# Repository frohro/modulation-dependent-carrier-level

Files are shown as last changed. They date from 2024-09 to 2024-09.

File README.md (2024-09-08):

# AWR MDCL Board
The YSE50 Amplitude Modulation Compandor (AMC) board for the ABB (ASEA Brown Bovari) SK-52 transmitters was redesigned  at AWR because we wanted a way to automatically reduce the transmitter power in real-time based on signal-to-noise ratio measurements in the target area.  It also provides us an opportunity to change the modulation-dependent carrier level (MDCL) automatically in real-time, based on the program content and/or the signal-to-noise ratio in the target area.  

This design should work with any transmitter using an ABB PSM (pulse step modulator) for AM or SW broadcasting designed in the 1980s or 1990s. It replaces the YSE 50 or YSE 21 PCBs in the PSM.  I suspect it should work with any transmitter using the YSE 21 or YSE 50.  These boards cost around \\$90,000 around the turn of the century, but you should be able to build this one for about $150 each in 2024, the most expensive parts are the DIN connectors that mate the board to the transmitter.  These boards are far better, because they use software to do the MDCL and facilitate experimentation and optimization.

## MDCL
Adventist World Radio (AWR) on Guam uses modulation-dependent carrier level (MDCL) which is a way of modifying the transmitted AM signal so it uses less power than standard amplitude modulation while hopefully not reducing the listenership.  AM was designed so receivers could be built easily and inexpensively using the technology available in the early 20th century.  A sinusoid at the radio frequency would be modulated (have its amplitude adjusted) as the desired audio signal, $m(t)$, went up and down.  If the radio frequency (RF) sine wave was $A cos(\omega_c t)$ and the audio signal to be transmitted was $m(t)$ where $|m(t)| < 1$, the transmitted signal, $v(t)$ is given by $A(1+m(t))cos(\omega_c t)$. Keeping the magnitude of the audio signal less than one makes $m(t)$ easy to remove from $v(t)$ with an envelope detector enabling very simple receivers to be constructed.  Unfortunately, there is no information in the $1$ term of $(1 + m(t))$, but it does take energy to send it.  If the audio is very soft so that $m(t) << 1$, and the goal is to transmit the information in $m(t)$, it seems especially wasteful.  (Note: Even a public address system playing an analog audio signal like $m(t)$ isn't an equal cost per bit of information.  Loud signals require more power, but they don't always contain more information.  Sometimes the quiet whisper of a friend is worth far more than the loud talk going on.  But for AM modulation the $1$ term has almost nothing to do with the $m(t)$, so it indeed seems a waste to send, at least in a certain sense.)

There are two different types of MDCL, Dynamic Carrier Control (DCC) and Amplitude Modulation Companding (AMC).  

### DCC
DCC reduces the $1$ term in $1 + m(t)$, so less carrier power is transmitted when less is needed, keeping the percentage modulation closer to 100% where the peaks of $m(t) = 1$.   The  DCC signal would be $v_{DCC}(t) = A(k(t)+m(t))cos(\omega_c t)$ .  Because the factor $k < 1$ DCC saves some energy that would have been sent in the carrier perhaps unnecessarily.  It is a slowly varying function of time compared to $m(t)$, so we often think of it as a constant, just $k$. Suppose $k$ was reduced to zero when $m(t) = 0$, then other interfering signals would likely be heard by the receiver instead of silence because most receivers have automatic gain control (AGC) which adjusts the gain up when the signal goes down.  To combat this, $k$ is not usually reduced all the way down to zero.  This leaves a flat carrier for silence, which is usually strong enough that the small noise will be masked out and the receiver will produce silence.

All MDCL schemes use a fast attack slow decay signal based on the absolute value of the modulation signal.  If $m(t)$ quickly gets louder, the changes we make to the RF signal need to respond quickly, but if $m(t)$ decreases in amplitude we should respond slowly to minimize artifacts of our signal processing.  So the first step in doing MDCL is to construct this signal.  We call this signal $m_p(t) = f(|m(t)|)$ where $f$ is the fast attack, slow decay function of time.  In the old analog days, a circuit like this where the capacitor is charged based on the $R_{attack} C$ time-constant and decays based on the $R_{decay} C$ time-constant.  (Rob, replace this figure when you get your tablet-PC going again.)
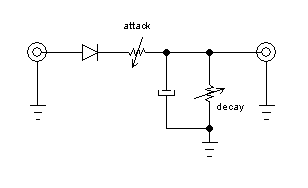
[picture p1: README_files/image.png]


would have been used.

Below, you can see how $k$ is computed as a function of $m_p(t)$ for DCC.  This function is somewhat heuristic.  The one shown is used in the YSE21 board.  Sometimes $k$ goes back up for low values of $m_p(t)$ to help silence be silent in a real receiver in the presence of interference.

```python
import matplotlib.pyplot as plt
import numpy as np

# Define the x values
x = np.linspace(0, 1, 500)

# Define the y values based on the condition
y = np.piecewise(x, [x < 0.5, x >= 0.5], [0.5, lambda x: (x-0.5)+0.5])

# Create the plot
plt.plot(x, y)

# Label the axes
plt.xlabel('$m_p(t)$')
plt.ylabel('k')

# Set the range for the axes
plt.xlim(0, 1)
plt.ylim(0, 1)

plt.title('DCC Carrier Level, k')

# Display the plot
plt.show()
```

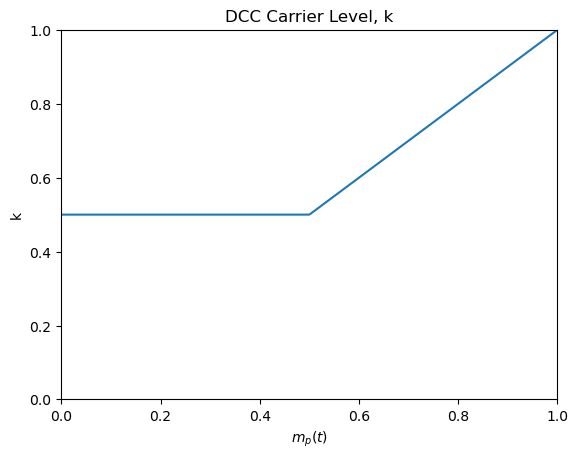
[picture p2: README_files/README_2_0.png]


### AMC
AMC takes the view that the soft or silent portions of the broadcast are more important to preserve than the loud portions.  This may be more appropriate for music rather than talk.  It adjusts the amplitude of $v(t)$, instead of just the carrier, as a function of $m_p(t)$ so  $v_{AMC} = A (A_{REL}(1+m(t)))$.  The following graph shows $A_{REL}$ as a function of $m_p(t)$.  Note again, that makes $A_{REL}$ a function of $t$, but since it is relatively slowly varying compared with $m(t)$, so we just call it $A_{REL}$.  

```python
# Define the x values
x = np.linspace(0, 1, 500)

# Define the y values based on the condition
y = np.piecewise(x, [x < 0.1, x >= 0.1], [1, lambda x: (-0.5/.9*x+1+.1*.5/.9)])

# Create the plot
plt.plot(x, y)

# Label the axes
plt.xlabel('$m_p(t)$')
plt.ylabel('$A_{REL}$')

# Set the range for the axes
plt.xlim(0, 1)
plt.ylim(0, 1.1)

plt.title('AMC Relative Signal Level, $A_{REL}$')

# Display the plot
plt.show()
```

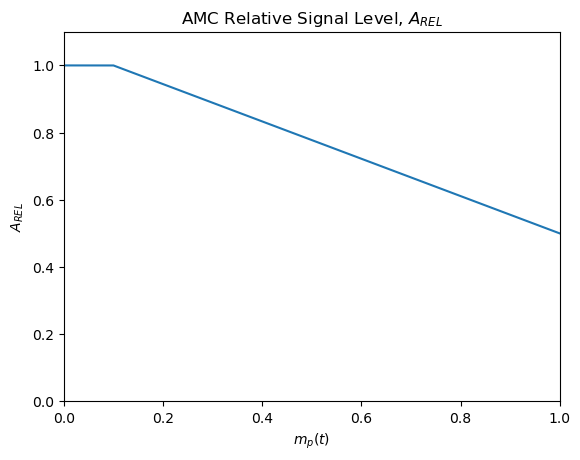
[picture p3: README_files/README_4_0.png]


AMC peak output power of the transmitter is the same as the output from the carrier alone.  For example, an SK-52 transmitter with a normal AM power level specified at 100 kW, means the carrier alone will output 100 kW average power.  On peak modulation, the output will be 400 kW because the $m(t)$ adds to the $1$ to become $2$ for 100% modulation at peaks of $m(t)$ giving $4$ times the power because power is proportional to the square of the voltage which is twice what it was for the carrier alone.  AMC thus saves power and wear and tear on the transmitter, by reducing the average power it is transmitting under larger modulation.  

There are variations on these two themes of MDCL one can dream about.  It is claimed that AMC is better for music, while DCC is better for speech.  AMC is more popular with medium wave AM stations.  It may sound better at least to some.  DCC only reduces carrier power, and that really doesn't contain any information other than silence.  Previous experiments with DCC indicated it actually sounds louder to the listener due to the way the receiver AGC and the transmitter DCC interact which is good for short wave.  AMC will save the station more money than DCC, but so would simply turning the power down.  Turning the power down is the major improvement we wish to add to the options, so we can use AMC, DCC, or ordinary AM, but only the power needed.  In the past it was not easy to measure how much power was needed, but now with Internet connected receivers, it can be done fairly easily.  Since the space weather changes the signal levels for skywave signals, this will change over time, so there will be times when less power is needed than the maximum possible.  In general a cut in power by half is only barely perceptible to the listener, so significant savings on the power bill can be expected.  The plan is to measure the signal-to-noise ratio every 15 minutes or so and change the transmitter power as appropriate.

## Transmitter Operation
AWR Guam has five ABB SK-52 100 kW transmitters.  They use the standard modulation method, where the B+ high voltage on the plate of the final amplifiers is supplied by the modulator, which produces an amplified version of the output of the MDCL output signal.  By varying this voltage on the plate of the final RF amplifier, the output signal’s amplitude is set.  This is called modulating the transmitter.   See the diagram below.
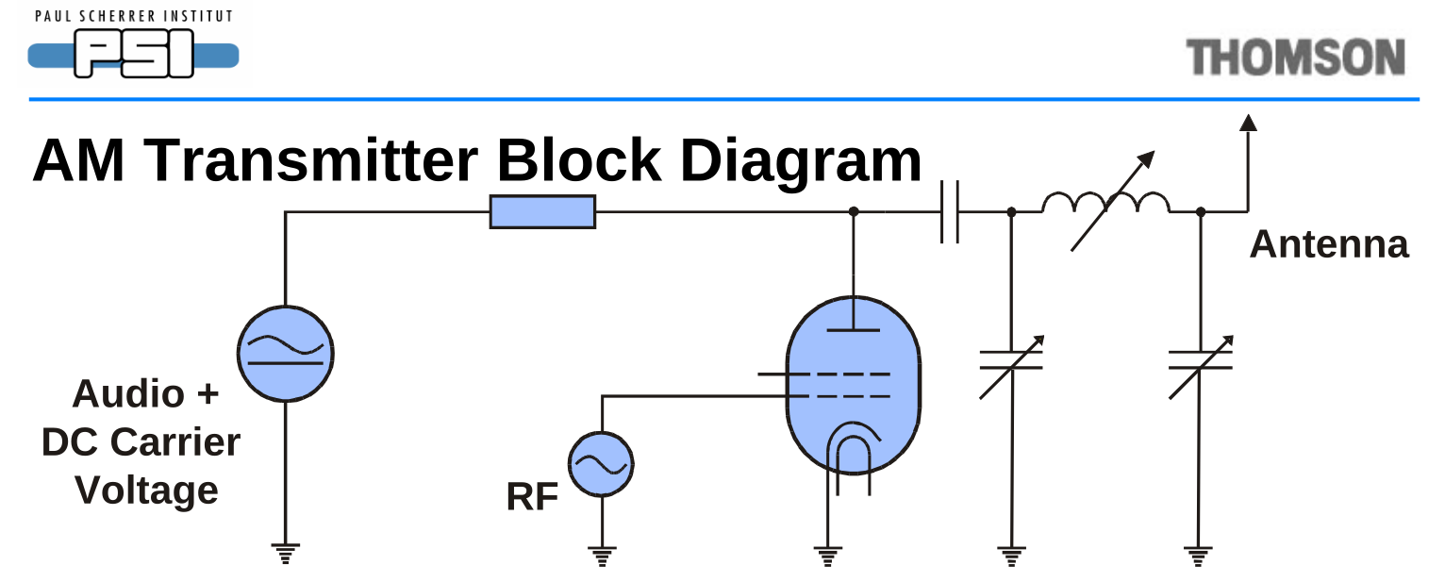
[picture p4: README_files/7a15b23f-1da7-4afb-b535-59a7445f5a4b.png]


A Pulse Step Modulator (PSM) is used to create the “Audio + DC Carrier Voltage” in the diagram above.  The PSM is essentially like a digital to analog converter where 26 voltage sources are switched in series by digital signals.  It is like a 26 level digital to analog converter with an output of 22 kV maximum.  When the AM transmitter (no MDCL) is sending silence, the PSM puts out 11 kV.  At 100% modulation where the $max (|m(t)|) = 1$, it puts out between 0 and 22 kV as the audio, $m(t)$ goes up and down.  Below is a basic diagram of a PSM.  The switches are controlled digitally and in the SK-52 are gate turn off (GTO) devices.  The blue, green, magenta and orange circular symbols are voltage sources.  (Rob, to avoid copyright, we could replace these when you have your bricked computer back.)
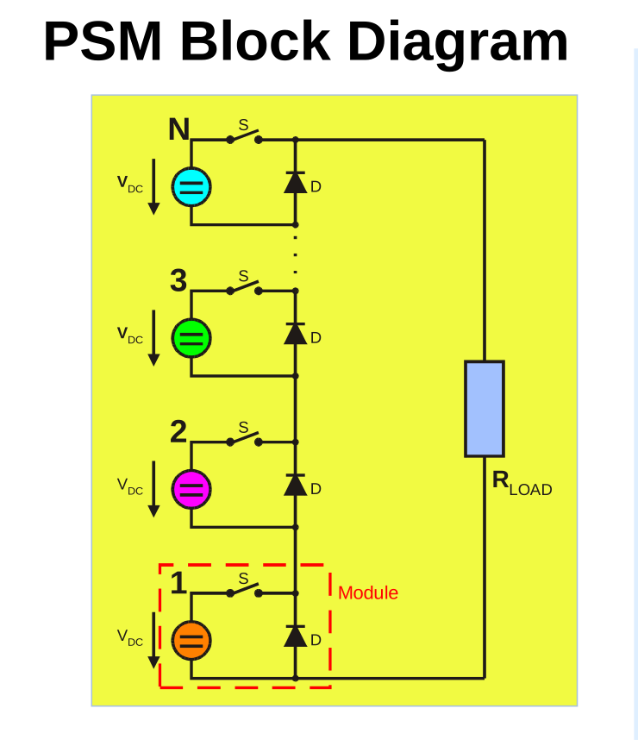
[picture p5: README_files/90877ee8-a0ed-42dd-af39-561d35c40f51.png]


The most obvious place in the circuit to incorporate a modification to the SK-52 transmitters is in the MDCL board, so YS50 was replaced.  The MDCL board is where something can be incorporated into the circuit to lower the power when a remote Internet connected receiver in the target area indicates the transmitter could cut power without significantly lowering the number of listeners.  We just add one more parameter we can control that multiplies whatever type of audio signal we have by a slowly varying "constant", that changes perhaps every 15 minutes as the signal-to-noise ratio is updated.  If this constant is called $A_{att}$, it would have a maximum value of $1$ for maximum power, and $0.707$ for half power, or $0.5$ for quarter power.  

Note in the blue AM Transmitter Block Diagram above, the screen grid in the vacuum tube.  Unless the voltage on the screen is also controlled by the MDCL board, a risk exists that the screen current will increase beyond acceptable limits.  For example if the plate of the tube is at $0$ volts, and the screen at a higher voltage, the screen will act as the plate normally would and the screen current would be way to high.  This means there is a limit to how much we can drop $A_{att}$.  A solution to this problem is to increase the resistor between the screen supply and the screen.  We were able to drop the power to 25% of maximum.  (Rob, make sure this is correct.)

We also noted a problem with the PSM protection circuitry which styll needs to be ironed out.

The transmitter has a limit to how long the modulation, $m(t)$ can exceed a certain value, so that the transmitter is not operated beyond 100 kW for longer than is good for it.  This limit is enforced in the MDCL software as well.

## Board Description

### Hardware
The hardware is based on a [PJRC Teensy 4.1 development board](https://www.pjrc.com/store/teensy41.html).  It features a 600 MHz ARM Cortex-M7 processor with FPU, nice Arduino DSP library, a USB 2.0 port and Ethernet.  The data $1+m(t)$ comes in as a 5V TTL digital 12-bit parallel signal sampled at 100 kHz.  This signal is converted to a serial signal by a pair of 74LV165 parallel to serial conversion ICs.  These also convert the 5V TTL level signals of the input data to 3.3 V logic levels.  This serial data is read into the Teensy using SPI0.  The Teensy processes the signal as needed and sends the data to a serial to parallel conversion performed by a pair of 74ACHT595 ICs, which send the result on to the next board in the transmitter.  There is a CH340G that allows use of a second USB serial port for debugging (Serial2 for the Arduino) and four connectors for the inexpensive eight bit logic analyzers from China to read the serial and parallel data.  There are a number of LEDs for indicators and debugging and some provision for connecting other signals to the Teensy in case we overlooked something.  The Teensy we are using comes with Ethernet, and we send the real-time control signals over that medium.

The Teensy has a feature that may eventually be used to eliminate the analog stages of the whole broadcast system, making the whole system at KSDA digital, from the digital audio in all the way to the PSM of the transmitter.  This feature is the USB connector on the Teensy can be made to look just like a USB sound card for a computer operating at the 44.1 kHz sample rate. I have tested the Linux sample rate conversion library runing a sinc interpolator and it looks feasible to convert from 44.1 kHz to 100 kHz in real time, leaving about half the time between 100 kHz samples for DSP.  Optical USB extenders can be used to span the distance between the transmitters and the audio distribution computer.

### Software

#### Toolchain
You can build this with the Arduino IDE using Teensyduino or with VScode.  The latter gives you a nicer environment, but the former is quicker to set up.

#### Serial Input
The SPI (SPI0) is used for the serial data transfer of the input data.  The upper four bits of the 16 bit word should be zero.  If not, you have RFI or something bad happening.  The Teensy 4.1 supports a depreciated legacy way or doing the transactions, but also has the new recommend way.  Using that method, the speed can be increased from 12 MHz to 80 MHz.  The setup function shows how to set things up, and the ISR is shown below:
// ISR function called by the interrupt that is triggered by L1
// to process the new word from the transmitter
void receive2ByteWord() // Receive 16-bit word from SPI0
{                       // Select the slave device
  SPI.beginTransaction(spiSettings);
  digitalWrite(chipSelectPin0, LOW);
  // Send a dummy byte to initiate the SPI read and receive the 16-bit word
  uint16_t dummy = 0x00;
  receivedWord = SPI.transfer16(dummy); // Deselect the slave device
  digitalWrite(chipSelectPin0, HIGH);
  validWord = 1; // Indicates that the new 16-bit word is received and ready to process
  SPI.endTransaction();
}
#### Serial Output
The SPI1 bus is used for transferring data to the serial to parallel converter so the data will be ready for a parallel read by the transmitter.  Like the serial input, the setup function gets the SPI initialized and the following code is the ISR that happens when triggered by LC.
// ISR function called by the interrupt that is triggered by L5 to send the
// processed word to the transmitter (DCC board used LC, but L5 is faster)
void send2ByteWord()
{
  SPI1.beginTransaction(spiSettings);

  digitalWrite(chipSelectPin1, LOW); //  We are not using CS1.
  SPI1.transfer16(wordToSend);       // Send the 16-bit word to the transmitter
  digitalWrite(chipSelectPin1, HIGH);
  SPI1.endTransaction();
}
DCC and MDCL Processing
uint16_t processMDCL(uint16_t one_plus_m_t)
// See the MDCL.ipynb for the theory on this.
{ // This function takes a 16-bit word whose lower 12 bits is 1+m(t) and processes it according to the MDCL algorithm
  // We could put a check for overmodulation here if wanted (Check for repeated 0's)
  if (digitalRead(SSBOnOffPin) == LOW && digitalRead(NFBereitPin) == HIGH && digitalRead(DCCOnOffPin) == HIGH)
  { // if MCDL is on
    uint16_t m_p;
    static uint16_t m_pPrevious = 0;     // store the previous m_p(t) value
    static uint16_t samplesUntilDecay = samplesPerDecay; // This is the number of samples until the decay starts

    if (one_plus_m_t < 2048)           // Find |m(t)| value where 1 + m(t) scaled to 0 to 4095
    {
      m_p = 2048 - one_plus_m_t; // This should not overflow.
    }
    else
    {
      m_p = one_plus_m_t - 2048; // This should not overflow.
    }
    #ifdef DEBUG
    uint16_t m_p_a;
    m_p_a = m_p;  // mpa is for debugging.  It is m_p without the decay.
    #endif
    // m_p(t) needs to be a fast attack, slow decay function of time
    if (m_p <= m_pPrevious) // m_p is decreasing
    { 
      m_p = m_pPrevious; // m_p(t) should not decrease
      if (samplesUntilDecay > 0) // Will decay down to close to 0 (within samplesPerDecay) if m_p(t) is not increasing
      {
        samplesUntilDecay--;
      }
      else // sammples until decay is 0, so decay one step
      {
        if (m_p > 0) m_p--; // m_p should not be decreased below zero
        samplesUntilDecay = samplesPerDecay; // Reset the decay counter
      }
    }
    else // m_p in increasing so don't decay m_p(t).  It needs to rise instantly, but samplesPerDecay needs to be reset so it is ready for the next decay.
    {
      samplesUntilDecay = samplesPerDecay; // Reset the decay counter
    }
    m_pPrevious = m_p; // Store the current m_p(t) value for the next cycle
    if (currentMDCLNumber == 0) // DCC
    {
      if (digitalRead(DCCPin) != HIGH) // Change indicator LEDs if needed
      {
        digitalWrite(DCCPin, HIGH);
        digitalWrite(AMCPin, LOW);
      }
      uint16_t dccK; // See the graph of DCC k as a function of m_p(t).  We may want to pass the 430 and 1024 parameters in someday
      if (m_p > 1024)
      {
        dccK = m_p;
      }
      else if (m_p < 430) // Using curve as used for ABB high power transmitters (> 100 kW)
      {
        dccK = 1454 - m_p;  // 1454 = 1024 + 430
      }
      else
      {
        dccK = 1024;
      }
      return percentAdjust * ((dccK + one_plus_m_t)-2048); // percentAdjust is to turn the power down
    }
    else if (currentMDCLNumber == 1) // AMC
    {
      if (digitalRead(AMCPin) != HIGH) // Change the indicator LEDs if needed
      {
        digitalWrite(DCCPin, LOW);
        digitalWrite(AMCPin, HIGH);
      }
      {
        digitalWrite(DCCPin, LOW);
        digitalWrite(AMCPin, HIGH);
      }
      float AMC_REL = (2048 - m_p / 2)/2048.0;                        // This should not overflow.
      return percentAdjust * ((AMC_REL * one_plus_m_t)); // percentAdjust < 1, is to turn the power down
    }
  }
  return percentAdjust * one_plus_m_t; // If MDCL is off, just pass the word through adjusted for desired power output
}

#### Keeping from Damaging the Transmitter by Asking for Too Much Power
The PSM manual description of YSE27 (pages 42-44) describe how long a signal that would transmit more than 100 kW is allowed.  You cannot have more than 2500 for longer than 10 mS.  If it happens, then you need to drop to the carrier level (2048) until the signal goes below the carrier level.  At first I was unable to determine if YSE27 was before or after YSE21 (the DCC unit we are replacing) so we wrote a safety routine that kept the MDCL board from violating the conditions needed for a healthy transmitter described there.  There were still possibilities of a bug that this would not catch, so I went back and finally found that YSE21 is before YSE27 in the transmitter.  It makes more sense to put this check at the end of the line, not in the DCC section, so our code was redundant, and was a possible place for bugs.  The block diagram in section 5 of Volume 7 Schematic Diagrams AF Stages (PSM), YSE-27 documents this.  I am removing our redundant code to make the software simpler.  (Rob 9/2/24).  This relieves a fear that we could ask the transmitter for more power than it could handle and it would burn up.

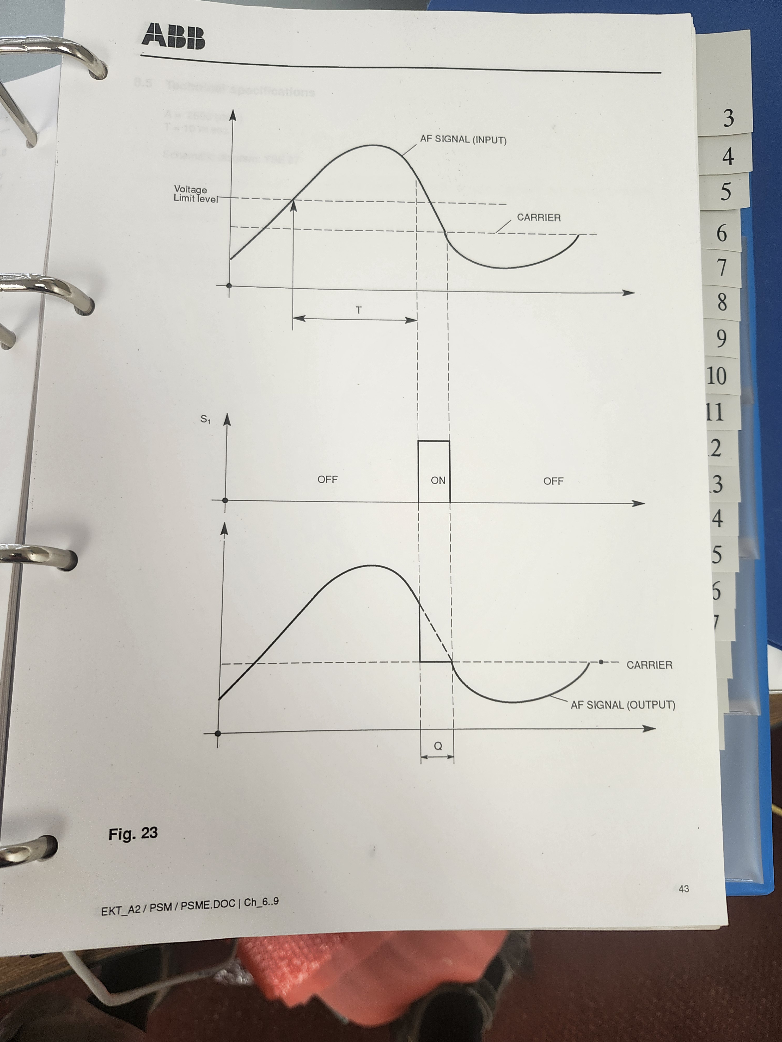
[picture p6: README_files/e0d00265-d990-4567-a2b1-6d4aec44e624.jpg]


#### Screen Modifications
The final tube screen voltage gets more and more attractive for electrons relative to the plate (anode) so an extra screen resistor was added to the screen power supply and possibly the voltage tap will be changed to reduce the screen voltage.

### Things Tested and Look Good
* SPI at 80 MHz both in and out good!
    * No data outside the 12 bit range like Ray had with the slower SPI
* Timing of SPI (input and output)
* Main loop usually happens every uS, but every 4th time it is 3.5 uS
* processMDCL with dontBurnTransmitterUP uses 300 nS (0.3 uS)  (fast enough)
* MDCL works (tested using triangle under all conditions)
* Make sure if loop() is delayed, it just keeps sending out the same wordToSend.  This will cover short timing problems, where loop() gets delayed.  It does.  
* Watch out for RFI!
### Things to test
* Different MDCL types and power levels while listening to remote receivers
* Lower voltage taps on screen power supply
### Things to Improve
* The messages in TCP/IP communication are too long.
* The code quoted in this keeps improving, making this difficult to keep up to date.  We need a better way of documenting it.
### Priorities for Rob before leaving Guam in order of Priority
* Get the MDCL board running smoothly.  Hopefully we can be running it in one of the transmitters full time by the time I leave.
    * Investigate how different MDCL methods and power levels are seen from remote receivers.
    * Documentation for the MDCL board and videos
* Finish getting the PostgreSQL database going for automated monitoring.
* Get the automated power level software going.

## Operation
#### RFI
Beware of RFI.  The PSM in the transmitter gets ">OFF" errors (meaning it is taking too long to turn off PSM modules, which is bad because the switch (GTO) dissipates power whenever it is turning on or off and the energy dissipated depends on how quickly you switch).  These appear to be caused by RF feedback into the system through the MDCL board when it is on the extender board for testing.  So only test it with it inside the transmitter case if the test involves transmitting, and do not leave any cables connected to it because they act as antennas.  If cables must be connected, use ferrite torroids to suppress common mode RF and optical fiber instead of copper wires wherever possible.

Compute what the minimum power output will be with your MDCL and make sure it does not go below 10 kW.  We could put a test in the code to not send something below 648.

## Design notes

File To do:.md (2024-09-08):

To do:
1) Clean up and refactor the code. (Make it organized, and have short files that each do their thing, and only that.)
    a) Make subprograms
        i) in seperate files
    b) Minimize global variables
    c) Make a seperate test program without all the other junk
    d) Document the programs carefully
    e) Test them
    f) Make debug code
        i) Use Serial3
        ii) Make a triangle or sine wave subprogram at 100 kHz sample rate
    g) Use Github Copilot to help organize this and speed things up (Get Ray up on it or do it yourself)
    h) Use variable names that are descriptive, match the documentation and go with that seperate block of code.
    i) Try to make the code simple, but not use too much time.
2) Learn how to operate the transmitter so two are not needed for testing (Rob)
3) Try 250 Ohm screen resistor
4) Minimize RFI possibility (No uneeded cables should be connected)
    a) Don't connect Ethernet until needed
        i) Perhaps use shorter cables or optical link.
    b) Don't connect the computer that is connected to the transmitter to power (run on batteries)
    c) Minimize the loop area for any ground loops
    d) Look for RFI with the scope
    e) Perhaps use ferrite beads if we find RFI somewhere and need to have the cable connected

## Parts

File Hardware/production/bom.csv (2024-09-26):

Designator | Footprint | Quantity | Value | LCSC Part #
C1, C11, C16, C17, C19, C2, C20, C4, C5, C6, C7, C8, C9 | 0805 | 13 | 0.1u | C49678
C10, C14 | 0603 | 2 | 10p | C1634
C18 | 0805 | 1 | 10u | C15850
D1 | D_SMA | 1 | SS14 | C2480
D10, D11, D12, D13, D3, D7, D8, D9 | 0603 | 8 | LED | C2290
D2, D4, D5, D6 | LED_3.0mm_2.54mm_lead_spacing_horizontal | 4 | HV-32H307B/260/XSYG
J1 | DIN41612_F_3x16_Male_Horizontal_THT | 1 | Top DIN
J10 | IDC-Header_2x05_P2.54mm_Vertical_SMD | 1 | Logic Analyzer SPI1 | C2843214
J11 | PinHeader_2x03_P2.00mm_Vertical_SMD | 1 | Ethernet Jack Socket | C3975167
J2 | DIN41612_F_3x16_Male_Horizontal_THT | 1 | Lower DIN
J3 | RJ45_Cetus_J1B1211CCD_Horizontal | 1 | J1B1211CCD | C910371
J4 | USB_Micro-Yuandi-G3P3-A1T2 | 1 | USB_B_Micro | C2682512
J5 | IDC-Header_2x05_P2.54mm_Vertical_SMD | 1 | Logic Analyzer SPI0 | C2843214
J6 | IDC-Header_2x05_P2.54mm_Vertical_SMD | 1 | Logic Analyzer D_In | C2843214
J7 | IDC-Header_2x05_P2.54mm_Vertical_SMD | 1 | Logic Analyzer D_Out | C2843214
J8, J9 | PinHeader_1x24_P2.54mm_Vertical | 2 | Teensy socket | C7506622
R1, R2, R3, R4 | 1206 | 4 | 75 | C17888
R10, R11, R12, R9 | 0603 | 4 | 470 | C23179
R5, R6, R7, R8 | 0805 | 4 | 100 | C17408
TP1, TP2 | TestPoint_THTPad_4.0x4.0mm_Drill2.0mm | 2 | GND
U1, U2 | TSSOP-16_4.4x5mm_P0.65mm | 2 | 74LV165 | C201716
U3, U4 | TSSOP-16_4.4x5mm_P0.65mm | 2 | 74AHCT595 | C554707
U5 | SOT-353_SC-70-5 | 1 | 74HC1G04GW,125 | C10234
U6 | SOP-16_3.9x9.9mm_P1.27mm | 1 | CH340G | C14267
U7 | TSSOP-24_4.4x7.8mm_P0.65mm | 1 | SN74LVC8T245 | C7859
Y1 | Crystal_SMD_2520-4Pin_2.5x2.0mm | 1 | 12 MHz | C963522

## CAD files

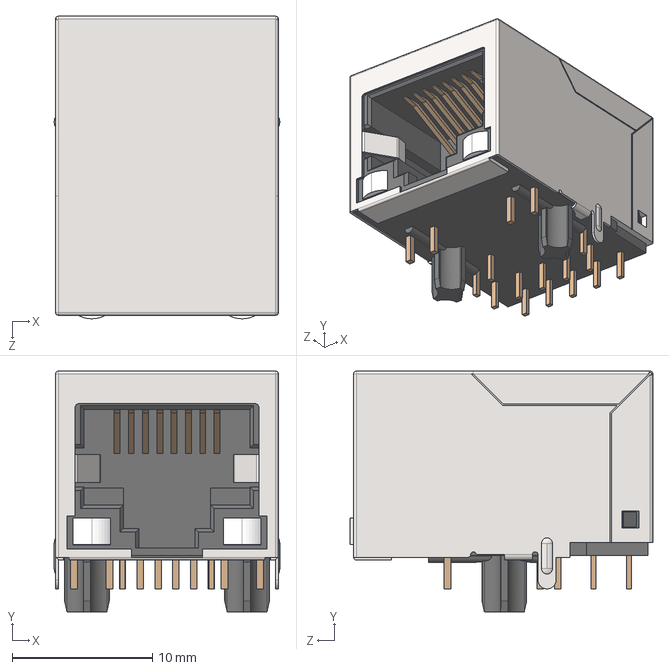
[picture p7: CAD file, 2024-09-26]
Hardware/RJ45 Connector with Integrated Magnetics.STEP
16.1 x 17.2 x 21.6 mm

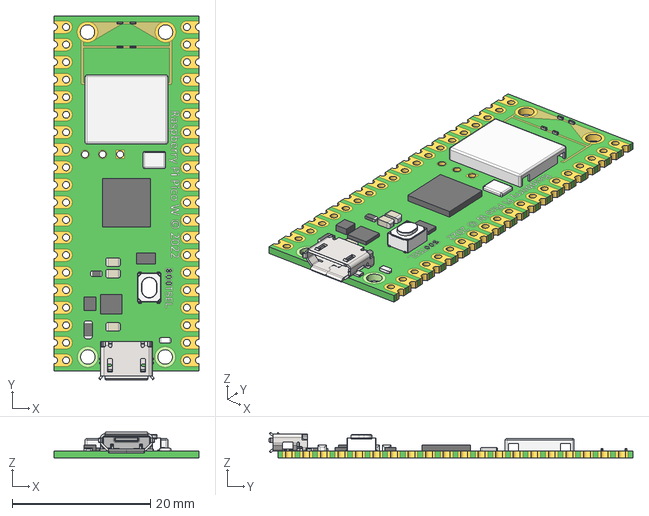
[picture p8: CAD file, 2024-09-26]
Hardware/RaspberryPi-PicoW-NoPins.step
21.0 x 52.7 x 3.71 mm

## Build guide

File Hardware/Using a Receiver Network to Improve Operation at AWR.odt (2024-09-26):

AWR Dynamic Power Control Project

Overview:

AWR’s station on Guam spends more than half a million dollars on electricity every year to spread the Gospel to countries in Asia broadcasting in the HF shortwave spectrum. Shortwave broadcasters lack the data which Internet media dissemination provides, such as how many listeners, etc., but it is not traceable like the Internet either. A person in North Korea can listen quietly under the covers with a lot less risk than using a computer or phone to listen online. AWR also buys time on other broadcast facilities around the world in places like Madagascar, Tajikistan, Austria, Germany, Uzbekistan, Taiwan, and Sri Lanka. They are paying far more to these stations than the cost of power on Guam. There is at present no regular monitoring of these stations to make sure they are delivering the programs they agreed to deliver to the prospective target areas. If you are interested, the program schedule is available here (https://awr.org/wp-content/uploads/2024/03/A24-AWR-Public-Broadcast-Schedule.pdf). The resources available online have multiplied in the past twenty years. For a number of years there have been a number of software defined radio receiver networks online that enable one to listen to shortwave radio with a web browser. For example, the KiwiSDR network is available here (http://rx.linkfanel.net/). There are receivers in AWR target areas that could be used to gather data about how well AWR can be heard. This data could be used in a number of ways.

- The data could be used to make sure the programs are receivable in the target areas.
- The data could be used to help make up the program schedule each season.
- Shortwave propagation varies with the space weather. The exact location of the receiver is not as important as one might expect. For example, usually when stations in Europe are heard in Washington State, they are heard with very similar signal strengths all up and down the West Coast. Signal strengths vary as the earth rotates and sun shines on different areas of the ionosphere. At sunrise and sunset, this is very noticeable. Often the signal can vary by more than 20 dB. For a broadcaster to increase their signal by 20 dB, the power of the transmitter would need to be raised by two orders of magnitude. Sometimes the signal strength of an AWR transmission will be 20 dB louder than necessary. Other times, for example during an aurora event, the signals may not be discernible in the target area. Hopefully, this does not happen often, but it probably does occur occasionally. If the data available online giving the signal to noise ratio was sampled every few minutes, that data could be used to adjust the transmitter power in “real time” so the signal was still good, but not unnecessarily strong. This could lower the power bill for AWR. For example, if AWR was 20 dB louder than needed, the power could be cut by a factor of 100 while that condition prevailed.
- AWR uses 4x4 dipole curtain antenna arrays. Presently, they steer the beam of the antenna in the horizontal direction using switched delay lines to target different areas. It is possible that steering the beam in the vertical direction could improve AWR’s signal in the desired target area. Online receivers could be used to investigate this, and if it varies with HF propagation conditions, it could be adjusted in real time along with the power.
- The receiver network could also be used to adjust the modulation dependent carrier level (MDCL) used in the transmitters.

The first priority for my time on Guam is to make the transmitters so the power can be controlled by a computer signal. After studying the transmitter it appears the best way to do that is to replace the MDCL board.

MDCL:

AWR uses modulation dependent carrier level (MDCL) which is a way of modifying the transmitted AM signal so it uses less power. Standard amplitude modulation (AM) was designed so receivers could be built easily and inexpensively using the technology available in the early 20th century. A sinusoid at the radio frequency would be modulated (have its amplitude adjusted) as the desired audio signal, m(t), went up and down. If the radio frequency (RF) sine wave was { cos left ( { %omega_c ~ t } right ) } and the audio signal to be transmitted was { m left ( t right ) } where |m(t)| < 1, the transmitted signal, v(t) is given by A ( 1 + m(t) ) cos(%omega_c t) . Keeping the magnitude of the audio signal less than one makes m(t) easy to remove from v(t) and enabled very simple receivers to be constructed. Unfortunately, there is no information in the 1 term of (1 + m(t)), because it does take energy to send it. If the audio is very soft so than m(t) << 1, and the goal is to transmit the information in m(t), it is especially wasteful.

There are two different types of MDCL, Dynamic Carrier Control (DCC) and Amplitude Modulation Companding (AMC).

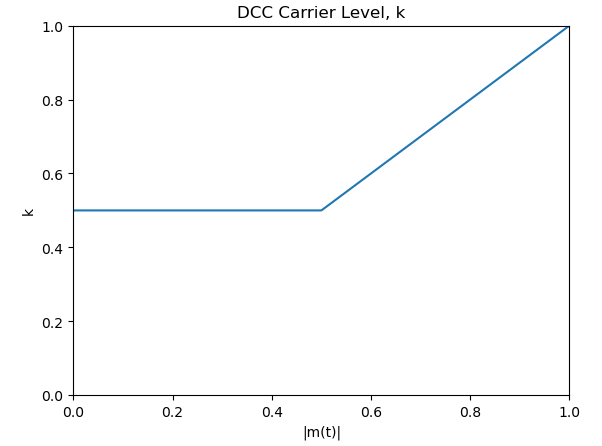
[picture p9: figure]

DCC reduces the 1 term in v(t), so less carrier power is transmitted when less is needed, keeping the same amount of m(t) transmitted so that the magnitude of m(t) was always less than or equal to the new constant, k, creating the “carrier”. The DCC signal would be v_{DCC}(t) = A ( k + m(t) ) . If k was reduced to zero when m(t) = 0, other interfering signals would likely be heard by the receiver instead of silence, because most receivers have automatic gain control (AGC) which adjusts the gain up when the signal goes down. To combat this, k is not usually reduced all the way down to zero. This leaves a flat carrier for silence, that will usually be strong enough that the small noise will be masked out and the receiver will produce silence. The graph on the previous page shows how the carrier level, k, was adjusted in the first DCC circuit the present transmitters on Guam used.

AMC takes the view that the soft or silent portions of the broadcast are more important to preserve than the loud portions. This may be more appropriate for music rather than talk. It adjusts the amplitude of v(t), instead of just the carrier, as a function of |m(t)| so v_{AMC}(t) = A (A_{REL}) ( 1 + m(t) ) .

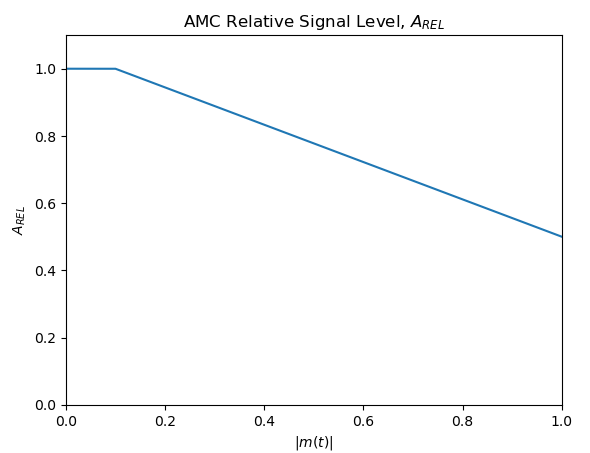
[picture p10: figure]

In recent years AWR has been using AMC, even though its programming is primarily talk instead of music because it reduced their power bill more than DCC would have. This is because AMC reduces the whole signal, not just the carrier, so the part of the signal carrying information is also reduced when it is louder. The actual information would have been better transferred with DCC, but the differences are only slight. Both ways reduce the power bill. Using remote receivers we may be able to tell what the best algorithm and adjustment is best. Furthermore, we could use AI to recognize the type of program being broadcast, music or speech, and perhaps change the MDCL as a function of the program type.

MDCL generally has a fast attack, slow decay, so it gradually turns the power down, and quickly turns it back up.

Transmitter Operation:

AWR Guam has five ABB SK-52 100 kW transmitters. They use the standard modulation method, where the B+ high voltage on the plate of the final amplifiers is supplied by the modulator, which produces an amplified version of the output of the MDCL output signal. By varying this voltage on the plate of the final RF amplifier, the output signal’s amplitude is set. This is called modulating the transmitter. See the diagram below.


A Pulse Step Modulator (PSM) is used to create the “Audio + DC Carrier Voltage” in the diagram above. The PSM is essentially like a digital to analog converter where 26 voltage sources are switched in series by digital signals. It is like a 26 level digital to analog converter with an output of 22 kV maximum. When the AM transmitter (no MDCL) is sending silence, the PSM puts out 11 kV. At 100% modulation (|m(t)| = 1) it puts out between 0 and 22 kV as the audio goes up and down. Below is a basic diagram of a PSM. The switches are controlled digitally. The blue, green, magenta and orange circular symbols are voltage sources.


Each module is switched so that they are each on the same percentage of the time. Since there are only 26 steps with this situation, pulse width modulation is used on one of the voltage sources to remove the quantization noise. The general details can be seen in this PowerPoint presentation (https://www3.aps.anl.gov/News/Conferences/2006/CWHAP06/presentations/Tron.pdf).

How to change the power output of the transmitter:

There is a power regulator circuit in these transmitters to keep the carrier level in standard AM constant. You can continuously adjust the power level using it, and at first we thought this was how we could turn the transmitter power up and down. After more study and experimentation, we determined that the regulator is only operational in “DSB”, what ABB calls standard AM modulation (not double sideband suppressed carrier). The regulator is disabled when MDCL is used or when transmitting single sideband (SSB). (SSB uses envelope elimination and restoration (EER), not linear amplification.) Experiments indicate the MDCL circuit will vary the power output anywhere between about 10 kW and 100 kW. The MDCL board takes 12 bits of audio plus carrier (DC) signal in, and according to the type of MDCL selected, varies the digital audio output which is also 12 bits at 100 kS/s. There is a clock that tells the MDCL board when the digital data is ready to be read, and and another tells it when it is time to send the last processed digital signal out. There are a few inputs to control whether MDCL is active too that must be monitored. The most recent MDCL board is described it an attachment. It uses two Altera FPGAs and cost AWR $90,000. We have no source code for the FPGA. We do have the schematic for the previous DCC board and it uses discrete logic ICs and EPROMs. (See attachments.) I might have been tempted to use a Raspberry Pi Pico W to do the processing, but my experience trying to read audio data from the I2S buss of an ADC and send it over WIFI or the UART would not work at more than 48 kHz at 16 bits per sample, so I decided to use a regular Raspberry Pi 5 computer running Linux. There are not enough GPIO to read and write the data in a parallel fashion, so we are using shift registers and reading it into the Pi serially. The Pi uses 3.3V logic, so we are using 74LV and 74AHCT chips for the data input and output of the Pi respectively. Other signals have a bidirectional logic level shifter. The physical dimensions of the space available dictate that the Ethernet and USB ports of the Pi will have to stick out the front of the transmitter. This should not be a big issue as there are plenty of other things sticking out like that already.

Things I am concerned about and questions I have:

- There are two clock domains, the Pi and the transmitter. I am trying to buffer them using the shift registers. Am I doing this correctly, and will there be any problems with this. I am not anywhere near as comfortable with the digital design as with analog design. What is wrong with our PCB design? We want to send it off fairly soon so we don’t lose too much time waiting for the boards.
- I plan to monitor the clocks with GPIO on the Pi and use them to create interrupts to read the digital signals.
- What is our board bring-up plan? Do we have the right test points and are there enough of them? Do we want a logic analyzer socket built into the board?
- We can do the DSP outside the ISRs. What problems will there be with this?
- The Pi running Linux is not real time. Is it fast enough?
- We want to make the maintenance needed as little as possible. The plan is to leave the same major version of Linux on the Pi. Can we get the security updates to automatically install? We can probably put a firewall on the Pi to only allow connection with remote receivers if needed, but this may need maintenance too. How do we best address this maintenance issue?
- How do we calibrate data from the receiver network so we get a good idea what the signal sounds like on a cheap SW receiver?
- AWR curtain arrays have about 20 dB gain. How do we calibrate the signals if we are using some that are not perfectly in the target area?
- If we cannot get data from the remote receivers, we can fall back to just running full power like we do now.
- How do we want to store the data we collect?
- Are there other uses we can make of this data?

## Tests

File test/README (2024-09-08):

This directory is intended for PlatformIO Test Runner and project tests.

Unit Testing is a software testing method by which individual units of
source code, sets of one or more MCU program modules together with associated
control data, usage procedures, and operating procedures, are tested to
determine whether they are fit for use. Unit testing finds problems early
in the development cycle.

More information about PlatformIO Unit Testing:
- https://docs.platformio.org/en/latest/advanced/unit-testing/index.html

I am using this for keeping code I just use for testing.

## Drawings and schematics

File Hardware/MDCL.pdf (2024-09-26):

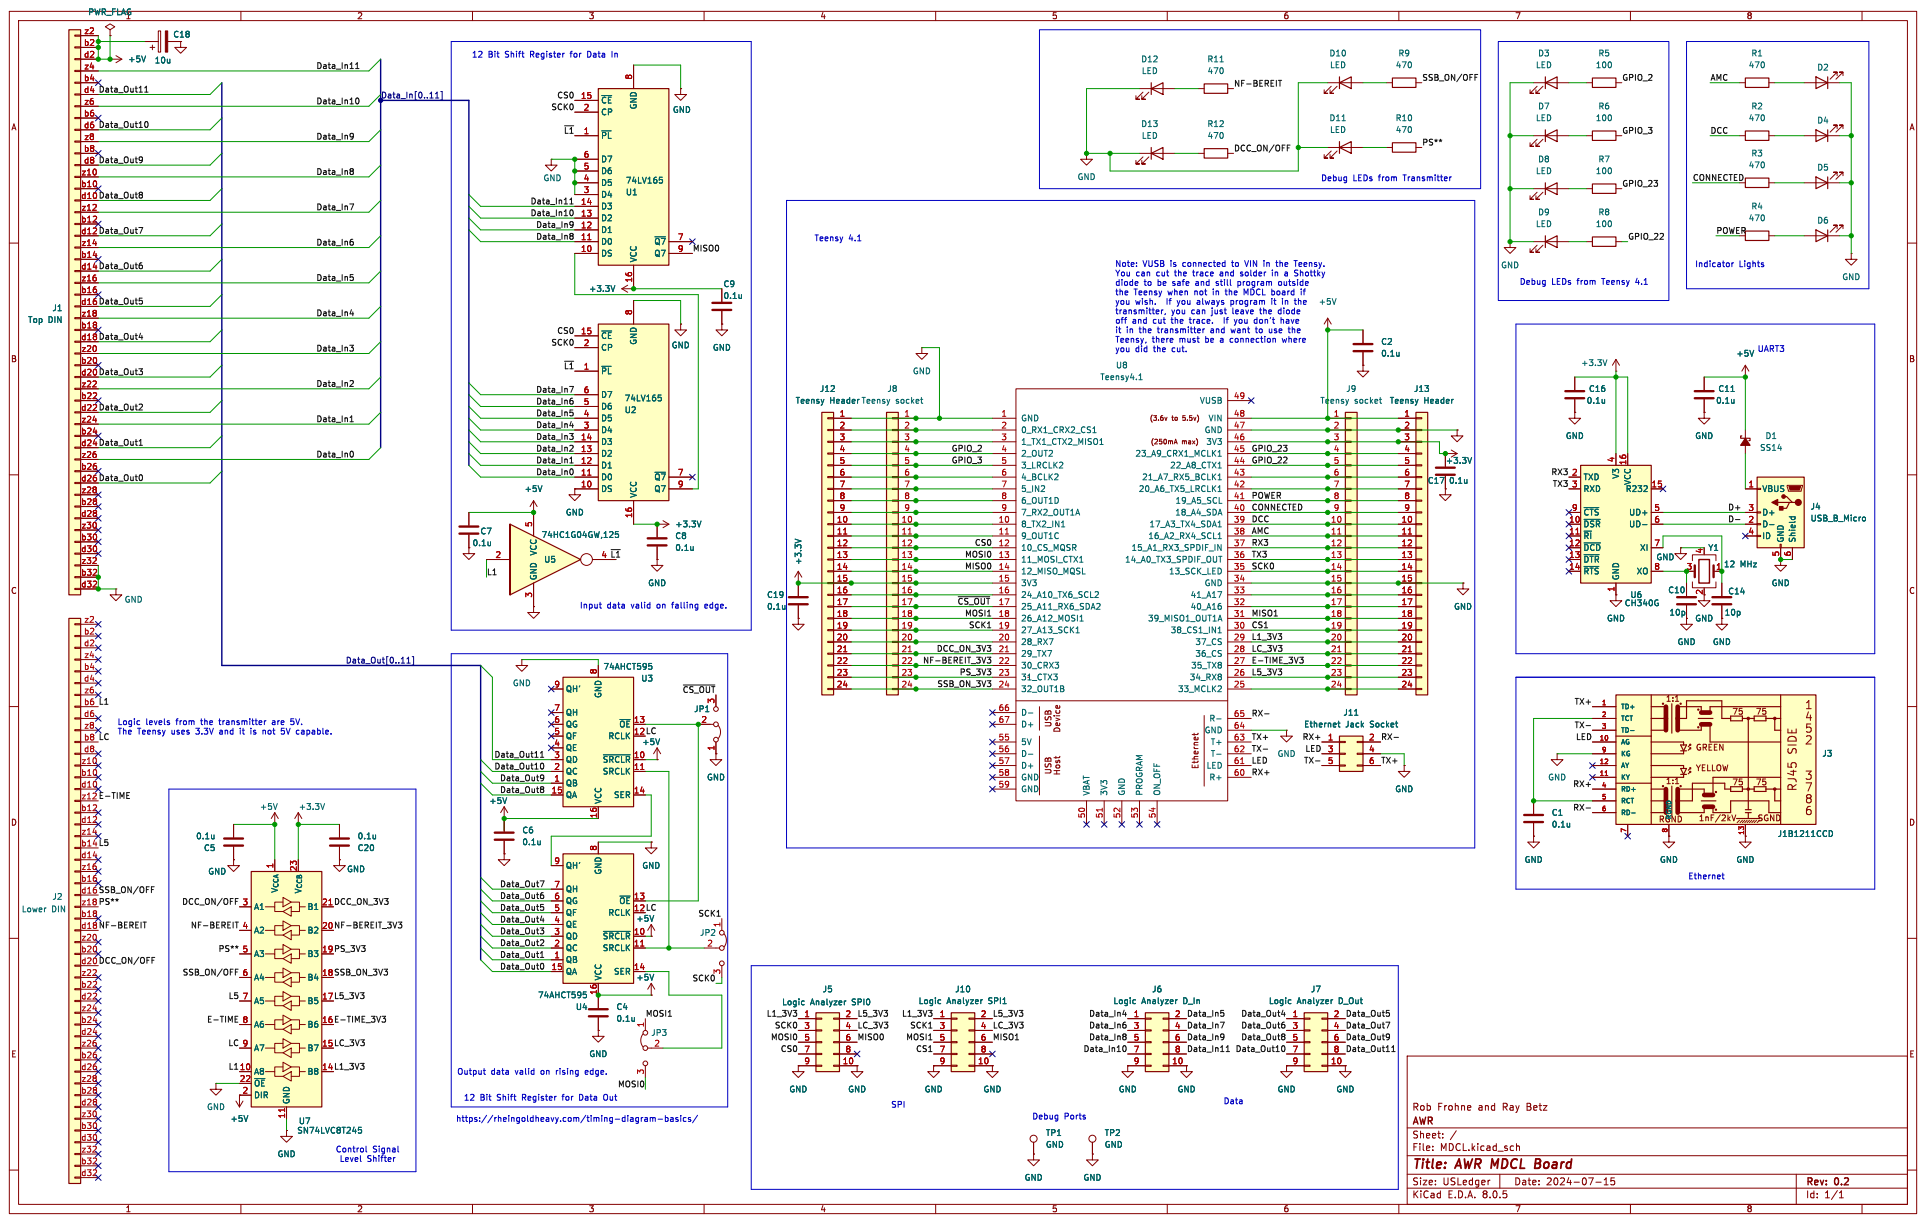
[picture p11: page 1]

12 Bit Shift Register for Data In

Debug LEDs from Transmitter

1 ~{DSR} 10 ~{RI} 11 ~{DCD} 12 ~{DTR} 13 ~{RTS} 14 R232 VCC

J11 Ethernet Jack Socket TP2 GND GND

File: MDCL.kicad_sch Sheet: / AWR

Id: 1/1 Title: AWR MDCL Board

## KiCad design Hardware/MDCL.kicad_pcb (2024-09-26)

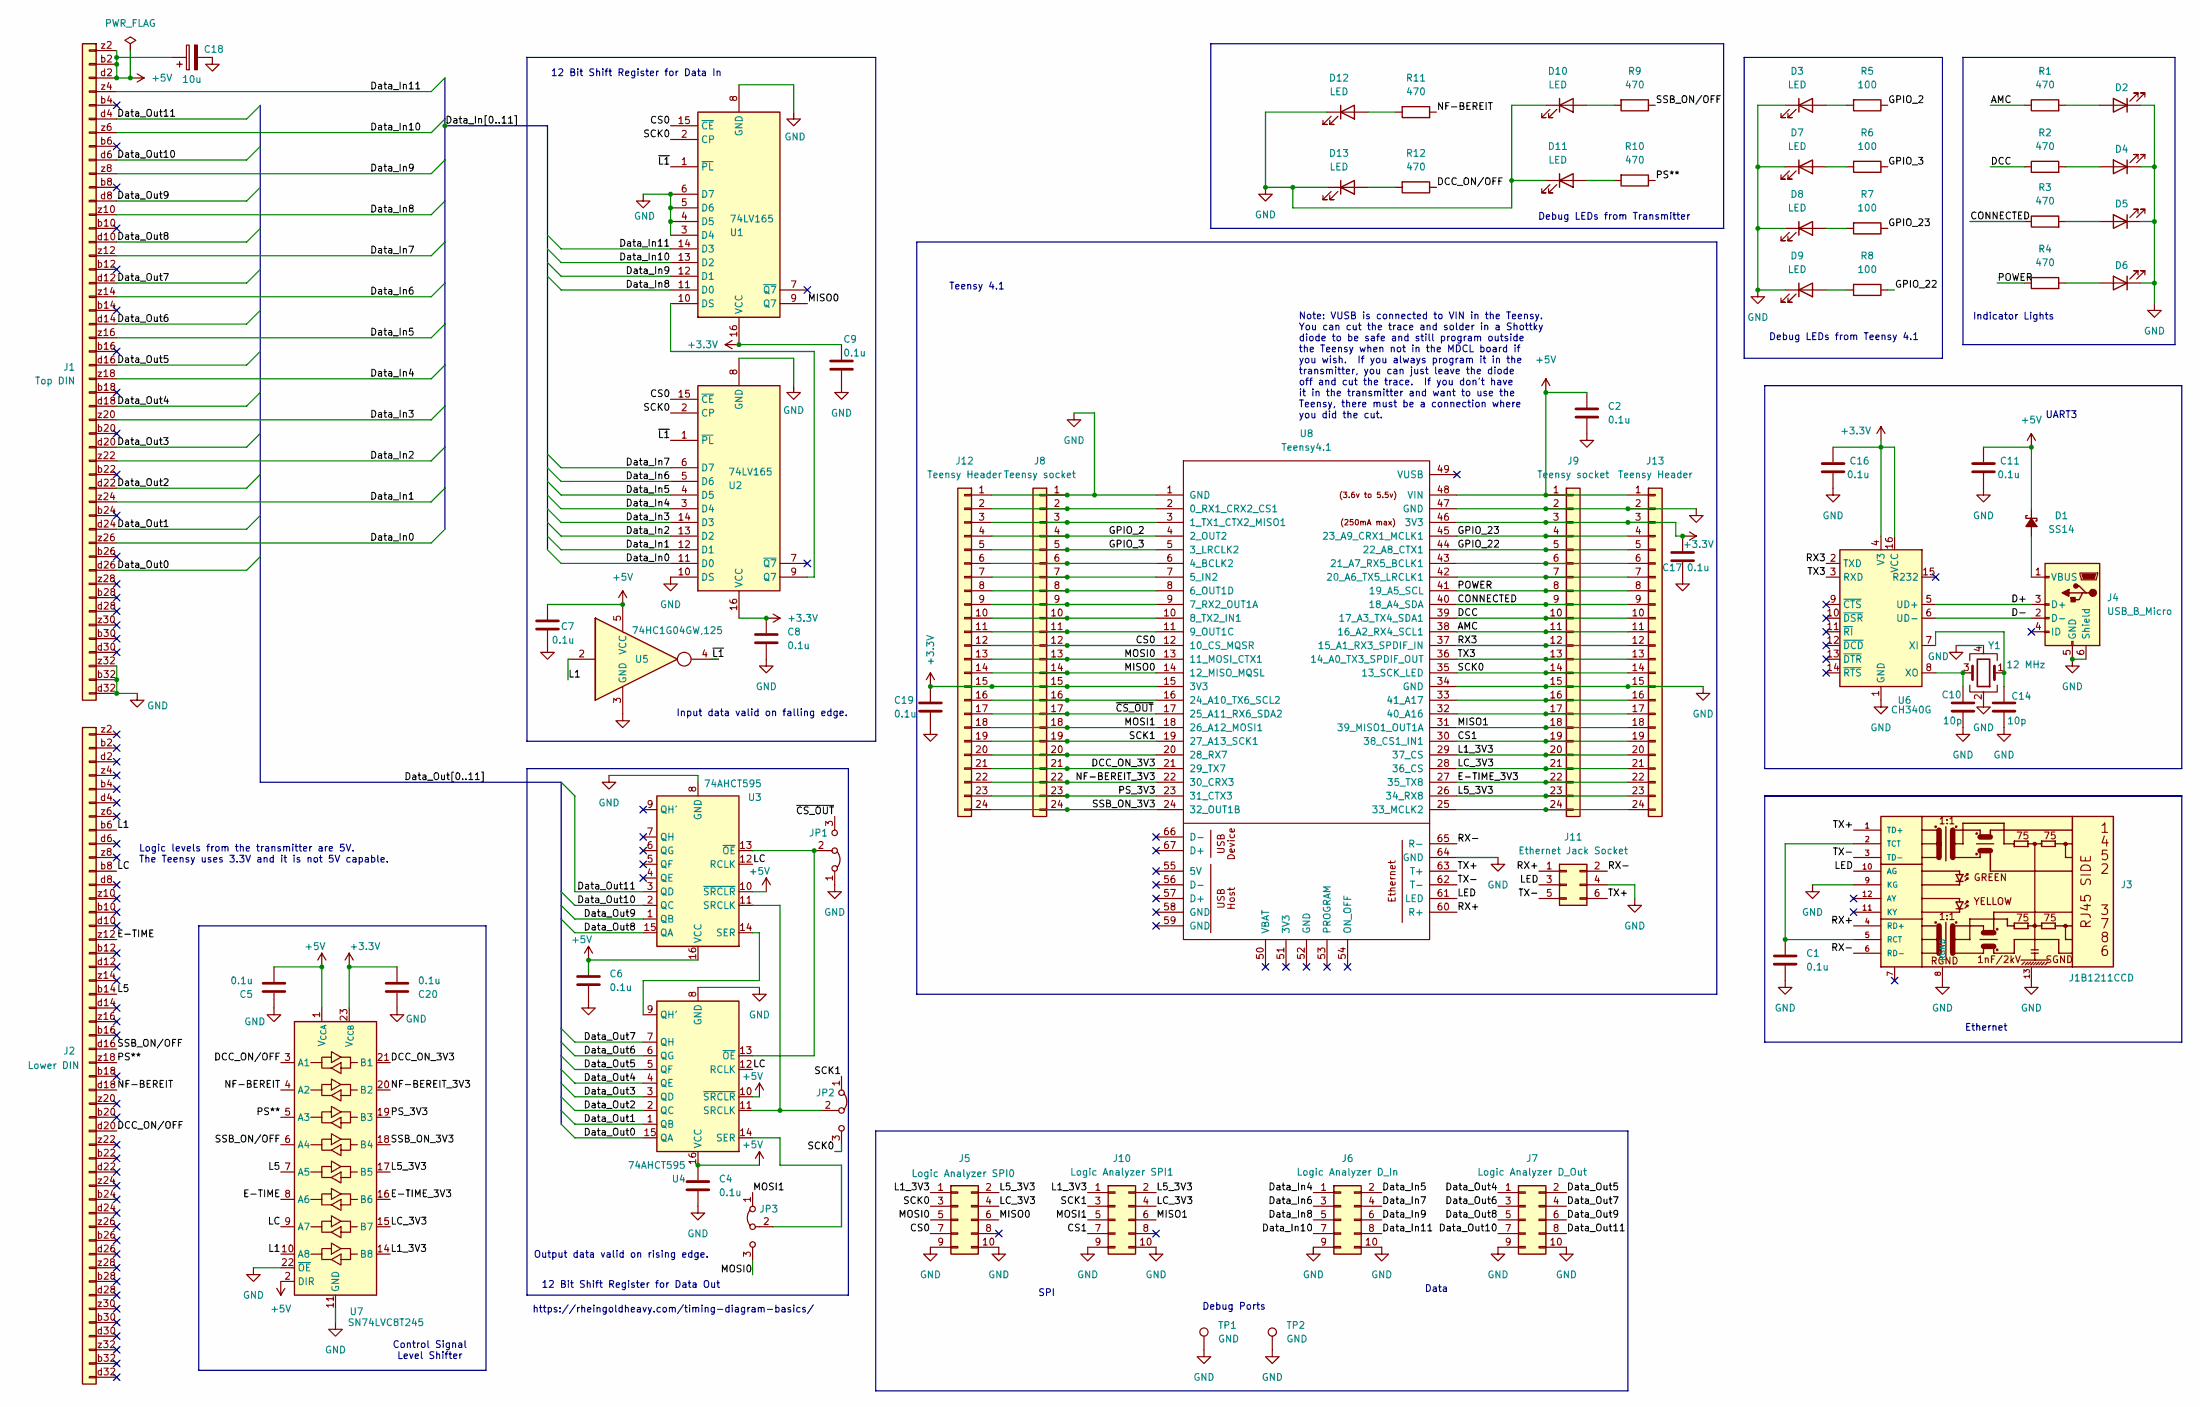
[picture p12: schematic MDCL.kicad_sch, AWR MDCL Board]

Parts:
C1, C2, C4, C5, C6, C7, C8, C9, C11, C16, C17, C19, C20: 0.1u; C_0805_2012Metric; LCSC C49678
C10, C14: 10p; C_0603_1608Metric; LCSC C1634
C18: 10u; C_0805_2012Metric; LCSC C15850
D1: SS14; D_SMA; LCSC C2480
D2, D4, D5, D6: HV-32H307B/260/XSYG; LED_3.0mm_2.54mm_lead_spacing_horizontal
D3, D7, D8, D9, D10, D11, D12, D13: LED; LED_0603_1608Metric; LCSC C2290
J1: Top DIN; DIN41612_F_3x16_Male_Horizontal_THT
J2: Lower DIN; DIN41612_F_3x16_Male_Horizontal_THT
J3: J1B1211CCD; RJ45_Cetus_J1B1211CCD_Horizontal; LCSC C910371
J4: USB_B_Micro; USB_Micro-Yuandi-G3P3-A1T2; LCSC C2682512
J5: Logic Analyzer SPI0; IDC-Header_2x05_P2.54mm_Vertical_SMD; LCSC C2843214
J6: Logic Analyzer D_In; IDC-Header_2x05_P2.54mm_Vertical_SMD; LCSC C2843214
J7: Logic Analyzer D_Out; IDC-Header_2x05_P2.54mm_Vertical_SMD; LCSC C2843214
J8, J9: Teensy socket; PinHeader_1x24_P2.54mm_Vertical; LCSC C7506622
J10: Logic Analyzer SPI1; IDC-Header_2x05_P2.54mm_Vertical_SMD; LCSC C2843214
J11: Ethernet Jack Socket; PinHeader_2x03_P2.00mm_Vertical_SMD; LCSC C3975167
J12, J13: Teensy Header; PinHeader_1x24_P2.54mm_Vertical
JP1, JP2, JP3: Jumper_3_Bridged12; SolderJumper-3_P1.3mm_Bridged12_RoundedPad1.0x1.5mm_NumberL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
R1, R2, R3, R4: 470; R_1206_3216Metric; LCSC C17936
R5, R6, R7, R8: 100; R_0805_2012Metric; LCSC C17408
R9, R10, R11, R12: 470; R_0603_1608Metric; LCSC C23179
TP1, TP2: GND; TestPoint_THTPad_4.0x4.0mm_Drill2.0mm
U1, U2: 74LV165; TSSOP-16_4.4x5mm_P0.65mm; LCSC C201716
U3, U4: 74AHCT595; TSSOP-16_4.4x5mm_P0.65mm; LCSC C554707
U5: 74HC1G04GW,125; SOT-353_SC-70-5; LCSC C10234
U6: CH340G; SOP-16_3.9x9.9mm_P1.27mm; LCSC C14267
U7: SN74LVC8T245; TSSOP-24_4.4x7.8mm_P0.65mm; LCSC C7859
U8: Teensy4.1
Y1: 12 MHz; Crystal_SMD_2520-4Pin_2.5x2.0mm; LCSC C963522

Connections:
+3.3V: C8.1, C9.1, C16.1, C17.1, C19.1, C20.2, J8.15, J9.3, J12.15, J13.3, U1.16 (VCC), U2.16 (VCC), U6.4 (V3), U6.16 (VCC), U7.23 (V_{CCB}), U7.24 (V_{CCB}), U8.15 (3V3), U8.46 (3V3)
+5V: C2.1, C4.1, C5.2, C6.1, C7.1, C11.1, C18.1, D1.1 (K), J1.b2, J1.d2, J1.z2, J9.1, J13.1, U3.10 (~SRCLR), U3.16 (VCC), U4.10 (~SRCLR), U4.16 (VCC), U5.5 (VCC), U7.1 (V_{CCA}), U7.2 (DIR), U8.48 (VIN)
/AMC: J9.11, J13.11, R1.1, U8.38 (16_A2_RX4_SCL1)
/CONNECTED: J9.9, J13.9, R3.1, U8.40 (18_A4_SDA)
/CS0: J5.7, J8.12, J12.12, U1.15 (~CE), U2.15 (~CE), U8.12 (10_CS_MQSR)
/CS1: J9.19, J10.7, J13.19, U8.30 (38_CS1_IN1)
/D+: J4.3 (D+), U6.5 (UD+)
/D-: J4.2 (D-), U6.6 (UD-)
/DCC: J9.10, J13.10, R2.1, U8.39 (17_A3_TX4_SDA1)
/DCC_ON_3V3: J8.21, J12.21, U7.21 (B1), U8.21 (29_TX7)
/DCC_ON/OFF: J2.d20, R12.1, U7.3 (A1)
/Data_In0: J1.z26, U2.11 (D0)
/Data_In1: J1.z24, U2.12 (D1)
/Data_In2: J1.z22, U2.13 (D2)
/Data_In3: J1.z20, U2.14 (D3)
/Data_In4: J1.z18, J6.1, U2.3 (D4)
/Data_In5: J1.z16, J6.2, U2.4 (D5)
/Data_In6: J1.z14, J6.3, U2.5 (D6)
/Data_In7: J1.z12, J6.4, U2.6 (D7)
/Data_In8: J1.z10, J6.5, U1.11 (D0)
/Data_In9: J1.z8, J6.6, U1.12 (D1)
/Data_In10: J1.z6, J6.7, U1.13 (D2)
/Data_In11: J1.z4, J6.8, U1.14 (D3)
/Data_Out0: J1.d26, U4.15 (QA)
/Data_Out1: J1.d24, U4.1 (QB)
/Data_Out2: J1.d22, U4.2 (QC)
/Data_Out3: J1.d20, U4.3 (QD)
/Data_Out4: J1.d18, J7.1, U4.4 (QE)
/Data_Out5: J1.d16, J7.2, U4.5 (QF)
/Data_Out6: J1.d14, J7.3, U4.6 (QG)
/Data_Out7: J1.d12, J7.4, U4.7 (QH)
/Data_Out8: J1.d10, J7.5, U3.15 (QA)
/Data_Out9: J1.d8, J7.6, U3.1 (QB)
/Data_Out10: J1.d6, J7.7, U3.2 (QC)
/Data_Out11: J1.d4, J7.8, U3.3 (QD)
/E-TIME: J2.z12, U7.8 (A6)
/E-TIME_3V3: J9.22, J13.22, U7.16 (B6), U8.27 (35_TX8)
/GPIO_2: J8.4, J12.4, R5.1, U8.4 (2_OUT2)
/GPIO_3: J8.5, J12.5, R6.1, U8.5 (3_LRCLK2)
/GPIO_22: J9.5, J13.5, R8.1, U8.44 (22_A8_CTX1)
/GPIO_23: J9.4, J13.4, R7.1, U8.45 (23_A9_CRX1_MCLK1)
/L1: J2.b6, U5.2, U7.10 (A8)
/L1_3V3: J5.1, J9.20, J10.1, J13.20, U7.14 (B8), U8.29 (37_CS)
/L5: J2.b14, U7.7 (A5)
/L5_3V3: J5.2, J9.23, J10.2, J13.23, U7.17 (B5), U8.26 (34_RX8)
/LC: J2.b8, U3.12 (RCLK), U4.12 (RCLK), U7.9 (A7)
/LC_3V3: J5.4, J9.21, J10.4, J13.21, U7.15 (B7), U8.28 (36_CS)
/LED: J3.10 (AG), J11.3, U8.61 (LED)
/MISO0: J5.6, J8.14, J12.14, U1.9 (Q7), U8.14 (12_MISO_MQSL)
/MISO1: J9.18, J10.6, J13.18, U8.31 (39_MISO1_OUT1A)
/MOSI0: J5.5, J8.13, J12.13, JP3.3 (B), U8.13 (11_MOSI_CTX1)
/MOSI1: J8.18, J10.5, J12.18, JP3.1 (A), U8.18 (26_A12_MOSI1)
/NF-BEREIT: J2.d18, R11.1, U7.4 (A2)
/NF-BEREIT_3V3: J8.22, J12.22, U7.20 (B2), U8.22 (30_CRX3)
/POWER: J9.8, J13.8, R4.1, U8.41 (19_A5_SCL)
/PS**: J2.z18, R10.1, U7.5 (A3)
/PS_3V3: J8.23, J12.23, U7.19 (B3), U8.23 (31_CTX3)
/RX3: J9.12, J13.12, U6.2 (TXD), U8.37 (15_A1_RX3_SPDIF_IN)
/RX+: J3.4 (RD+), J11.1, U8.60 (R+)
/RX-: J3.6 (RD-), J11.2, U8.65 (R-)
/SCK0: J5.3, J9.14, J13.14, JP2.3 (B), U1.2 (CP), U2.2 (CP), U8.35 (13_SCK_LED)
/SCK1: J8.19, J10.3, J12.19, JP2.1 (A), U8.19 (27_A13_SCK1)
/SSB_ON_3V3: J8.24, J12.24, U7.18 (B4), U8.24 (32_OUT1B)
/SSB_ON/OFF: J2.d16, R9.1, U7.6 (A4)
/TX3: J9.13, J13.13, U6.3 (RXD), U8.36 (14_A0_TX3_SPDIF_OUT)
/TX+: J3.1 (TD+), J11.6, U8.63 (T+)
/TX-: J3.3 (TD-), J11.5, U8.62 (T-)
/~CS_OUT: J8.17, J12.17, JP1.3 (B), U8.17 (25_A11_RX6_SDA2)
/~L1: U1.1 (~PL), U2.1 (~PL), U5.4
GND: C1.2, C2.2, C4.2, C5.1, C6.2, C7.2, C8.2, C9.2, C10.2, C11.2, C14.2, C16.2, C17.2, C18.2, C19.2, C20.1, D2.2 (K), D3.1 (K), D4.2 (K), D5.2 (K), D6.2 (K), D7.1 (K), D8.1 (K), D9.1 (K), D10.1 (K), D11.1 (K), D12.1 (K), D13.1 (K), J1.b32, J1.d32, J1.z32, J3.8 (RGND), J3.9 (KG), J3.13, J4.5 (GND), J4.6 (Shield), J5.9, J5.10, J6.9, J6.10, J7.9, J7.10, J8.1, J9.2, J9.15, J10.9, J10.10, J11.4, J12.1, J13.2, J13.15, JP1.1 (A), TP1.1, TP2.1, U1.3 (D4), U1.4 (D5), U1.5 (D6), U1.6 (D7), U1.8 (GND), U2.8 (GND), U2.10 (DS), U3.8 (GND), U4.8 (GND), U5.3 (GND), U6.1 (GND), U7.11 (GND), U7.12 (GND), U7.13 (GND), U7.22 (~OE), U8.1 (GND), U8.34 (GND), U8.47 (GND), U8.64 (GND), Y1.2, Y1.4
unnamed: D1.2 (A), J4.1 (VBUS)
unnamed: D2.1 (A), R1.2
unnamed: D3.2 (A), R5.2
unnamed: D4.1 (A), R2.2
unnamed: D5.1 (A), R3.2
unnamed: D6.1 (A), R4.2
unnamed: D7.2 (A), R6.2
unnamed: D8.2 (A), R7.2
unnamed: D9.2 (A), R8.2
unnamed: D10.2 (A), R9.2
unnamed: D11.2 (A), R10.2
unnamed: D12.2 (A), R11.2
unnamed: D13.2 (A), R12.2
unnamed: C1.1, J3.2 (TCT), J3.5 (RCT)
unnamed: J8.2, J12.2, U8.2 (0_RX1_CRX2_CS1)
unnamed: J8.3, J12.3, U8.3 (1_TX1_CTX2_MISO1)
unnamed: J8.6, J12.6, U8.6 (4_BCLK2)
unnamed: J8.7, J12.7, U8.7 (5_IN2)
unnamed: J8.8, J12.8, U8.8 (6_OUT1D)
unnamed: J8.9, J12.9, U8.9 (7_RX2_OUT1A)
unnamed: J8.10, J12.10, U8.10 (8_TX2_IN1)
unnamed: J8.11, J12.11, U8.11 (9_OUT1C)
unnamed: J8.16, J12.16, U8.16 (24_A10_TX6_SCL2)
unnamed: J8.20, J12.20, U8.20 (28_RX7)
unnamed: J9.6, J13.6, U8.43 (21_A7_RX5_BCLK1)
unnamed: J9.7, J13.7, U8.42 (20_A6_TX5_LRCLK1)
unnamed: J9.16, J13.16, U8.33 (41_A17)
unnamed: J9.17, J13.17, U8.32 (40_A16)
unnamed: J9.24, J13.24, U8.25 (33_MCLK2)
unnamed: JP1.2 (C), U3.13 (~OE), U4.13 (~OE)
unnamed: JP2.2 (C), U3.11 (SRCLK), U4.11 (SRCLK)
unnamed: JP3.2 (C), U4.14 (SER)
unnamed: U1.10 (DS), U2.9 (Q7)
unnamed: U3.14 (SER), U4.9 (QH')
unnamed: C14.1, U6.7 (XI), Y1.1
unnamed: C10.1, U6.8 (XO), Y1.3

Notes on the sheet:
Debug Ports
12 Bit Shift Register for Data In
Input data valid on falling edge.
https://rheingoldheavy.com/timing-diagram-basics/
Control Signal Level Shifter
UART3
Indicator Lights
Debug LEDs from Transmitter
Logic levels from the transmitter are 5V. The Teensy uses 3.3V and it is not 5V capable.
Ethernet
Data
Output data valid on rising edge.
12 Bit Shift Register for Data Out
Note: VUSB is connected to VIN in the Teensy. You can cut the trace and solder in a Shottky diode to be safe and still program outside the Teensy when not in the MDCL board if you wish. If you always program it in the transmitter, you can just leave the diode off and cut the trace. If you don't hav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
Teensy 4.1
SPI
Debug LEDs from Teensy 4.1

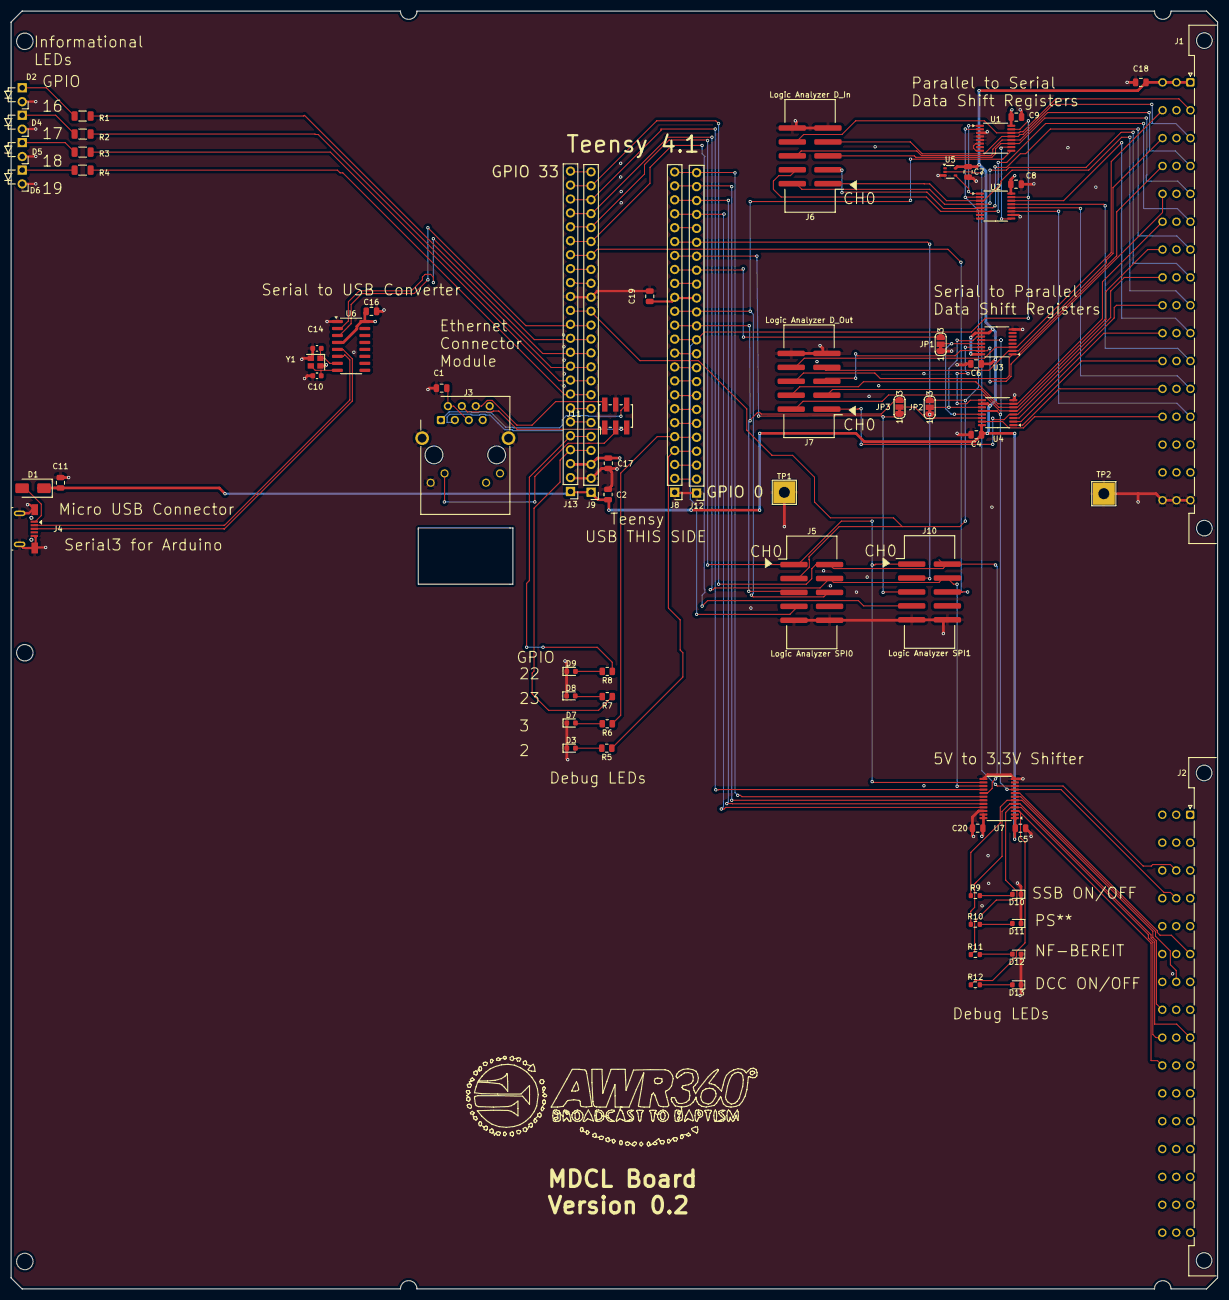
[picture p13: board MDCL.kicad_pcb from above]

Board: 4 copper layers, 220.0 x 233.0 mm, 67 parts (0 on the bottom side), 106 nets.

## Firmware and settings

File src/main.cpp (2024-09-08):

#define DEBUG

#include <Arduino.h>
#include <SPI.h>
#include <QNEthernet.h>
#include <globals.h>

using namespace qindesign::network;

// Define the IP address, subnet mask, and gateway
IPAddress ip(10, 7, 1, 12);     // Change to your desired IP
IPAddress sn(255, 255, 255, 0); // Subnet mask
IPAddress gw(10, 7, 1, 71);     // Default gateway

// Create a TCP server on port 5100
EthernetServer tcpServer(5100); // We probably don't want to use 5100.

const int L1Pin = 37;          // GPIO pin for L1, which indicates valid data for serial input to Teensy 4.1
const int LCPin = 36;          // GPIO pin for LC, which indicates when I can send data to the serial register for the next cycle
const int chipSelectPin0 = 10; // Chip select pin for SPI0
const int chipSelectPin1 = 38; // Chip select pin for SPI1
const int SSBOnOffPin = 32;    // Chip select pin for SPI0
const int NFBereitPin = 30;    // Chip select pin for SPI0
const int DCCOnOffPin = 29;    // Chip select pin for SPI0
const int powerPin = 19;       // pin connected to LED to show that board has power
const int connectedPin = 18;   // pin to show connected with the server
const int AMCPin = 16;         // used to activate LED to show AMC is being used
const int DCCPin = 17;         // used to activate LED to show DCC is being used
const int L5Pin = 34;          // GPIO pin for L5, which indicates when the Teensy 4.1 can send data to the transmitter

SPISettings spiSettings(80000000, MSBFIRST, SPI_MODE0); // 30 MHz, MSB first, SPI mode 0
// We can go to 80 MHz and the output shows it works.
// declare functions
void receive2ByteWord();
void send2ByteWord();
void getAndProcessMDCLTCPCommand(EthernetServer &tcpServer);
uint16_t processMDCL(uint16_t one_plus_m_t);
#ifdef DEBUG
// Debugging functions are here.  You can remove them later.
uint16_t generate_triangle_wave(uint16_t amplitude, uint32_t period_us);
void print_for_plot(uint16_t N, uint16_t variable1, const char* label1, 
                    uint16_t variable2 = 0, const char* label2 = "", 
                    uint16_t variable3 = 0, const char* label3 = "");
#endif 

// global variables
uint16_t receivedWord = 2048; // stores the 16 bit word coming from serial in
uint16_t wordToSend;          // stores word when it is ready to be sent to the transmitter
int samplesPerDecay = 10;      // Out of 4095, how much decay is there per sample for the slow decay of m_p(t)  1 is way to fast!
int validWord = 0;            // indicates the 16 bit word is ready to process 0 = not valid, 1 = valid
int currentMDCLNumber = 1;    // 0 = dcc, 1 = amc, 2 = other
float percentAdjust = 1;                                         ;      // range of 0 to 1 ... used to adjust overall voltage or power output of transmitter.
uint16_t processedWord;

// timer for sign wave
unsigned long startTime = micros();
unsigned long endTime;
unsigned long elapsedTime;
unsigned long timeForCycles = 1;
int count = 0;

void setup()
{
#ifdef DEBUG
  Serial.begin(9600);    // Serial port for debugging
  Serial3.begin(9600); // Extra debug port (/dev/ttyUSB0 or /dev/ttyUSB1 on linux)
#endif
  if (!Ethernet.begin(ip, sn, gw)) // Start Ethernet with a static IP
  {
#ifdef DEBUG
    Serial.println("Failed to start Ethernet");
#endif
    while (true)
      ; // Halt if Ethernet fails to start
  }
  tcpServer.begin(); // Start the TCP server
#ifdef DEBUG
  Serial.print("TCP Server is at ");
  Serial.println(Ethernet.localIP());
#endif
  // Initialize SPI0
  SPI.setMOSI(11); // Set MOSI pin for SPI0
  SPI.setMISO(12); // Set MISO pin for SPI0
  SPI.setSCK(13);  // Set SCK pin for SPI0
  SPI.begin();

  // Initialize SPI1
  SPI1.setMOSI(26); // Set MOSI pin for SPI1
  SPI1.setMISO(39); // Set MISO pin for SPI1
  SPI1.setSCK(27);  // Set SCK pin for SPI1
  SPI1.begin();

  pinMode(L1Pin, INPUT); // Set pin as input for L1
  pinMode(LCPin, INPUT); // Set pin as input for LC  // Not used presently.
  pinMode(L5Pin, INPUT); // Set pin as input for L5

  attachInterrupt(L1Pin, receive2ByteWord, FALLING); // Attach interrupt to pin, triggered on falling edge
  attachInterrupt(L5Pin, send2ByteWord, FALLING);    // Attach interrupt to pin, trigger on falling edge
  // Using L5 instead of LC because it has the data ready quicker for the transmitter.
  // L1 indicates the transmitter is ready, but this makes the data ready for sooner than L1, but still after
  // L1.
  // Set high priority for the interrupts
  // NVIC_SET_PRIORITY(IRQ_GPIO2_16_31, 0); // Highest priority for GPIO interrupts (L1Pin and LCPin)

  pinMode(AMCPin, INPUT);// Rob change this when 0 Ohm resistors are replaced with 470
  pinMode(DCCPin, INPUT);// Rob change this when 0 Ohm resistors are replaced with 470
  pinMode(powerPin, INPUT);// Rob change this when 0 Ohm resistors are replaced with 470
  pinMode(connectedPin, INPUT);  // Rob change this when 0 Ohm resistors are replaced with 470
  pinMode(chipSelectPin0, OUTPUT);
  pinMode(chipSelectPin1, OUTPUT);
  pinMode(SSBOnOffPin, INPUT);        //
  pinMode(NFBereitPin, INPUT);        //
  pinMode(DCCOnOffPin, INPUT);        //
  pinMode(22, OUTPUT);                // Debugging
  pinMode(23, OUTPUT);               // Debugging
  pinMode(2, OUTPUT);
  pinMode(3, OUTPUT);
  digitalWrite(chipSelectPin0, HIGH); // Ensure CS0 is high  (not really needed as we are not using it)
  digitalWrite(chipSelectPin1, HIGH); // Ensure CS1 is high
  digitalWrite(powerPin, HIGH);       // Show that power is on for the board
  // sei(); // Enable global interrupts
}

void loop() // This loop should take < 10 us to run or we are in trouble.
{
  if (validWord == 1) // check if new 16 bit word has been received from SPI0
  {
#ifdef DEBUG 
    //  wordToSend = 648;  // DC we can go to 700, but 512 is too low
    // The screen current trips.
    // wordToSend = processMDCL((uint16_t)(generate_triangle_wave(1000,1000))); // Process the received word (standard DSB)
    wordToSend = processMDCL(receivedWord); // Process the received word 
    if (wordToSend < 648) wordToSend = 648; // This is the minimum for the screen current to trip.
    // wordToSend = processMDCL((generate_triangle_wave(2000, 1000))); // Process the received word  
#endif
    validWord = 0; // wait until new word is received again
  }
  getAndProcessMDCLTCPCommand(tcpServer);
#ifdef DEBUG
  // digitalWrite(22, !digitalRead(22)); // Debugging
#endif
}

// ISR function called by the interrupt that is triggered by L5 to send the
// processed word to the transmitter (DCC board used LC, but L5 is faster)
void send2ByteWord()
{
  SPI1.beginTransaction(spiSettings);

  digitalWrite(chipSelectPin1, LOW); //  We are not using CS1.
  SPI1.transfer16(wordToSend);       // Send the 16-bit word to the transmitter
  digitalWrite(chipSelectPin1, HIGH);
  SPI1.endTransaction();
}

// ISR function called by the interrupt that is triggered by L1
// to process the new word from the transmitter
void receive2ByteWord() // Receive 16-bit word from SPI0
{                       // Select the slave device
  SPI.beginTransaction(spiSettings);
  digitalWrite(chipSelectPin0, LOW);
  // Send a dummy byte to initiate the SPI read and receive the 16-bit word
  uint16_t dummy = 0x00;
  receivedWord = SPI.transfer16(dummy); // Deselect the slave device
  digitalWrite(chipSelectPin0, HIGH);
  validWord = 1; // Indicates that the new 16-bit word is received and ready to process
  SPI.endTransaction();
}

uint16_t processMDCL(uint16_t one_plus_m_t)
// See the MDCL.ipynb for the theory on this.
{ // This function takes a 16-bit word whose lower 12 bits is 1+m(t) and processes it according to the MDCL algorithm
  // We could put a check for overmodulation here if wanted (Check for repeated 0's)
  if (digitalRead(SSBOnOffPin) == LOW && digitalRead(NFBereitPin) == HIGH && digitalRead(DCCOnOffPin) == HIGH)
  { // if MCDL is on
    uint16_t m_p;
    static uint16_t m_pPrevious = 0;     // store the previous m_p(t) value
    static uint16_t samplesUntilDecay = samplesPerDecay; // This is the number of samples until the decay starts

    if (one_plus_m_t < 2048)           // Find |m(t)| value where 1 + m(t) scaled to 0 to 4095
    {
      m_p = 2048 - one_plus_m_t; // This should not overflow.
    }
    else
    {
      m_p = one_plus_m_t - 2048; // This should not overflow.
    }
    #ifdef DEBUG
    uint16_t m_p_a;
    m_p_a = m_p;  // mpa is for debugging.  It is m_p without the decay.
    #endif
    // m_p(t) needs to be a fast attack, slow decay function of time
    if (m_p <= m_pPrevious) // m_p is decreasing
    { 
      m_p = m_pPrevious; // m_p(t) should not decrease
      if (samplesUntilDecay > 0) // Will decay down to close to 0 (within samplesPerDecay) if m_p(t) is not increasing
      {
        samplesUntilDecay--;
      }
      else // sammples until decay is 0, so decay one step
      {
        if (m_p > 0) m_p--; // m_p should not be decreased below zero
        samplesUntilDecay = samplesPerDecay; // Reset the decay counter
      }
    }
    else // m_p in increasing so don't decay m_p(t).  It needs to rise instantly, but samplesPerDecay needs to be reset so it is ready for the next decay.
    {
      samplesUntilDecay = samplesPerDecay; // Reset the decay counter
    }
    m_pPrevious = m_p; // Store the current m_p(t) value for the next cycle
    if (currentMDCLNumber == 0) // DCC
    {
      if (digitalRead(DCCPin) != HIGH) // Change indicator LEDs if needed
      {
        digitalWrite(DCCPin, HIGH);
        digitalWrite(AMCPin, LOW);
      }
      uint16_t dccK; // See the graph of DCC k as a function of m_p(t).  We may want to pass the 430 and 1024 parameters in someday
      if (m_p > 1024)
      {
        dccK = m_p;
      }
      else if (m_p < 430) // Using curve as used for ABB high power transmitters (> 100 kW)
      {
        dccK = 1454 - m_p;  // 1454 = 1024 + 430
      }
      else
      {
        dccK = 1024;
      }
      return percentAdjust * ((dccK + one_plus_m_t)-2048); // percentAdjust is to turn the power down
    }
    else if (currentMDCLNumber == 1) // AMC
    {
      if (digitalRead(AMCPin) != HIGH) // Change the indicator LEDs if needed
      {
        digitalWrite(DCCPin, LOW);
        digitalWrite(AMCPin, HIGH);
      }
      {
        digitalWrite(DCCPin, LOW);
        digitalWrite(AMCPin, HIGH);
      }
      float AMC_REL = (2048 - m_p / 2)/2048.0;                        // This should not overflow.
      return percentAdjust * ((AMC_REL * one_plus_m_t)); // percentAdjust < 1, is to turn the power down
    }
  }
  return percentAdjust * one_plus_m_t; // If MDCL is off, just pass the word through adjusted for desired power output
}

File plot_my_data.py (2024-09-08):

import pandas as pd
import matplotlib.pyplot as plt

def plot_serial_data(filename):
    # Initialize a dictionary to store the data
    data_dict = {}
    data_dict['time'] = []

    # Read the data from the file
    with open(filename, 'r') as file:
        for i, line in enumerate(file):
            values = line.strip().split(' ')
            if len(values) % 2 != 0:
                print(f"Skipping malformed line {i+1}: {line.strip()}")
                continue
            for j in range(0, len(values), 2):
                try:
                    label = values[j]
                    number = float(values[j+1])
                    if label not in data_dict:
                        data_dict[label] = []
                    data_dict[label].append(number)
                except (IndexError, ValueError) as e:
                    print(f"Error processing line {i+1}: {line.strip()} - {e}")
                    continue
            data_dict['time'].append(i * 10e-6)  # 10 microseconds interval

    # Convert the dictionary to a DataFrame
    data = pd.DataFrame(data_dict)

    # Plot the data
    plt.figure(figsize=(10, 6))
    for column in data.columns:
        if column != 'time':
            plt.plot(data['time'], data[column], label=column)

    plt.xlabel('Time (s)')
    plt.ylabel('Values')
    plt.title('Serial Data Plot')
    plt.legend()
    plt.grid(True)
    plt.show()

if __name__ == "__main__":
    filename = 'serial_data.txt'
    plot_serial_data(filename)
